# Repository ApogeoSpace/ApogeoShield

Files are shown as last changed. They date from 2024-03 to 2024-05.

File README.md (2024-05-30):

# ApogeoShield
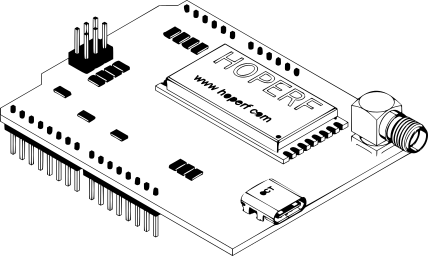
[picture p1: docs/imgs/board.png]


This repository hosts design files for an Arduino shield featuring a HopeRF RFM98 module, optimized for communication at 169 MHz. 
The project is developed by Apogeo Space Srl and allows users to connect and communicate via LoRa with the Apogeo Space IoT network with their own hardware.

## Building your shield

Feel free to utilize the provided files to construct your shields, ensuring compliance with the terms of our [license](LICENSE.md).

Please note that the project is built using KiCad 6, and while compatibility has been tested with later versions, successful importation to other CAD software is not guaranteed.

### BOM

While we do not provide specific sources for all the components needed; however, you can find the actual [BOM](bom.csv) and refer to it when sourcing components.

You can also open an issue or contact us directly for more information if you find it difficult to find certain components.

## What can I do with it?

Once you have built a shield, you can mount it on an Arduino Uno and use our [ApogeoNode](https://github.com/ApogeoSpace/ApogeoNode) library to connect to the Apogeo Space IoT network!

For further information or inquiries, please contact us.

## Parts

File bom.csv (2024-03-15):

Reference | Value | Datasheet | Footprint | Qty | DNP
J1 | Conn_02x03_Odd_Even | ~ | Connector_PinHeader_2.54mm:PinHeader_2x03_P2.54mm_Vertical | 1
J2 | Conn_Coaxial | ~ | Amphenol:SMA_Amphenol_901-143_Horizontal | 1
J4,J5 | Conn_01x06_Pin | ~ | Connector_PinHeader_2.54mm:PinHeader_1x06_P2.54mm_Vertical | 2
J6,J7 | Conn_01x08_Pin | ~ | Connector_PinHeader_2.54mm:PinHeader_1x08_P2.54mm_Vertical | 2
MOD1 | RFM98PW |  | Acies:XCVR_RFM98PW | 1
P1 | USB_C_Plug_USB2.0 | https://www.usb.org/sites/default/files/documents/usb_type-c.zip | Connettori_P:USB_C_Receptacle_GCT_USB4085 | 1
R6,R7,R8,R9 | 1K | ~ | Resistor_SMD:R_1206_3216Metric_Pad1.30x1.75mm_HandSolder | 4
RC1,RC2,RI1,RI2,RO1,RO2,RR2,RS2,RS5 | 560 | ~ | Resistor_SMD:R_1206_3216Metric_Pad1.30x1.75mm_HandSolder | 9
RD2 | 0 | ~ | Resistor_SMD:R_1206_3216Metric_Pad1.30x1.75mm_HandSolder | 1

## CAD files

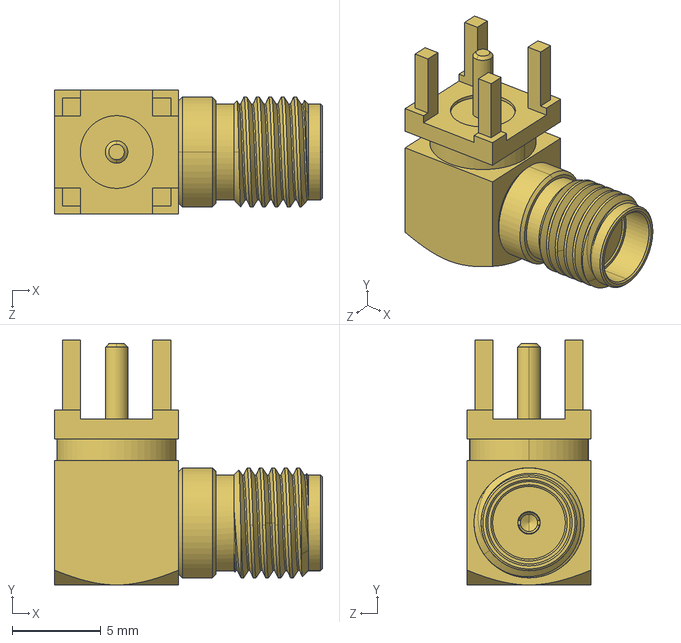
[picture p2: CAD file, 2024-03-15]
mdl/901-143-6RFX.stp
15.1 x 13.8 x 7.00 mm

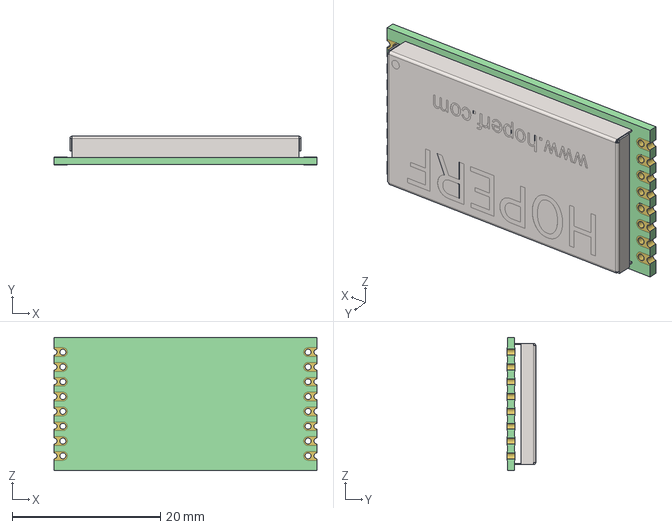
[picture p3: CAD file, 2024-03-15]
mdl/RFM98PW_RFM95PW.STEP
35.5 x 3.87 x 18.0 mm
RFM98PW_RFM95PW
RFM98PW_RFM95PW001

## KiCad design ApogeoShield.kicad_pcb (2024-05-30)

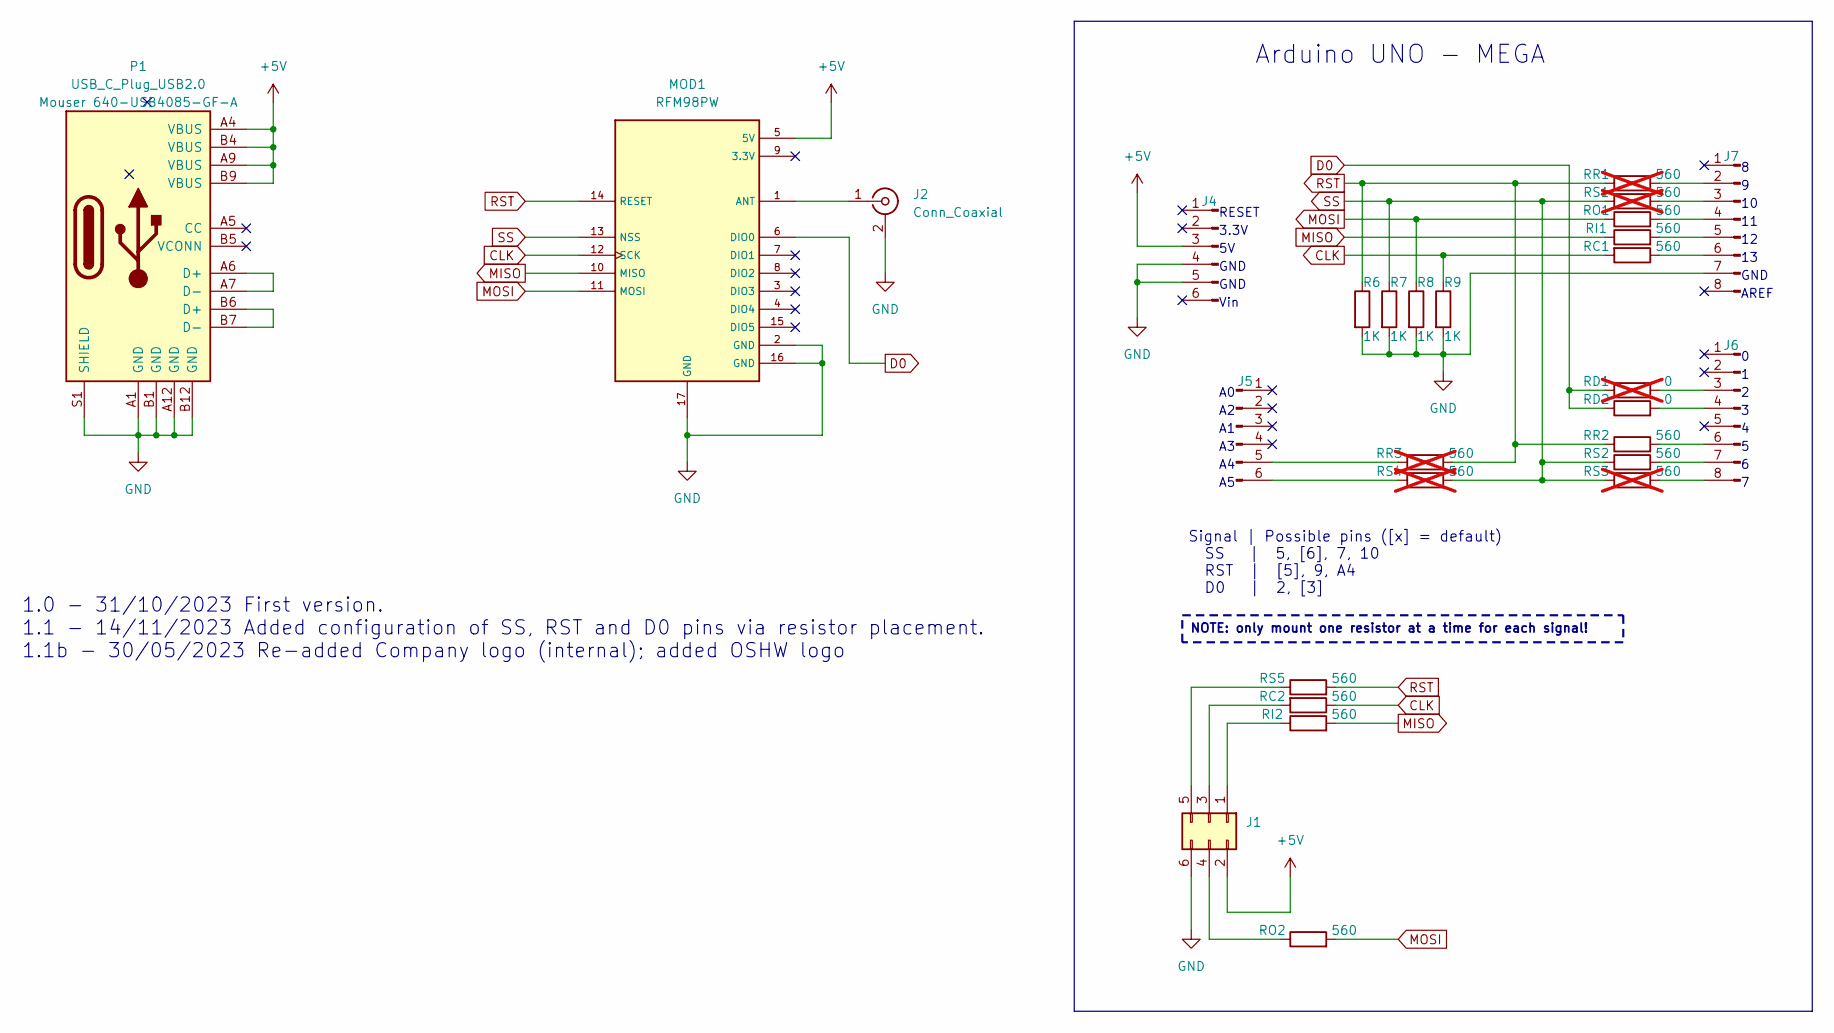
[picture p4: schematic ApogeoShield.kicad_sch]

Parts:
J1: Conn_02x03_Odd_Even; PinHeader_2x03_P2.54mm_Vertical
J2: Conn_Coaxial; SMA_Amphenol_901-143_Horizontal
J4, J5: Conn_01x06_Pin; PinHeader_1x06_P2.54mm_Vertical
J6, J7: Conn_01x08_Pin; PinHeader_1x08_P2.54mm_Vertical
MOD1: RFM98PW; XCVR_RFM98PW
P1: USB_C_Plug_USB2.0; USB_C_Receptacle_GCT_USB4085
R6, R7, R8, R9: 1K; R_1206_3216Metric_Pad1.30x1.75mm_HandSolder
RC1, RC2: 560; R_1206_3216Metric_Pad1.30x1.75mm_HandSolder
RD1: 0; R_1206_3216Metric_Pad1.30x1.75mm_HandSolder; not fitted
RD2: 0; R_1206_3216Metric_Pad1.30x1.75mm_HandSolder
RI1, RI2: 560; R_1206_3216Metric_Pad1.30x1.75mm_HandSolder
RO1, RO2: 560; R_1206_3216Metric_Pad1.30x1.75mm_HandSolder
RR1, RR3: 560; R_1206_3216Metric_Pad1.30x1.75mm_HandSolder; not fitted
RR2: 560; R_1206_3216Metric_Pad1.30x1.75mm_HandSolder
RS1, RS3, RS4: 560; R_1206_3216Metric_Pad1.30x1.75mm_HandSolder; not fitted
RS2, RS5: 560; R_1206_3216Metric_Pad1.30x1.75mm_HandSolder

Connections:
+5V: J1.2, J4.3, MOD1.5 (5V), P1.A4 (VBUS), P1.A9 (VBUS), P1.B4 (VBUS), P1.B9 (VBUS)
CLK: MOD1.12 (SCK), R9.1, RC1.2, RC2.1
D0: MOD1.6 (DIO0), RD1.1, RD2.1
GND: J1.6, J2.2 (Ext), J4.4, J4.5, J7.7, MOD1.2 (GND), MOD1.16 (GND), MOD1.17 (GND), P1.A1 (GND), P1.A12 (GND), P1.B1 (GND), P1.B12 (GND), P1.S1 (SHIELD), R6.2, R7.2, R8.2, R9.2
MISO: MOD1.10 (MISO), RI1.1, RI2.2
MOSI: MOD1.11 (MOSI), R8.1, RO1.1, RO2.2
unnamed: J1.1, RI2.1
unnamed: J1.3, RC2.2
unnamed: J1.4, RO2.1
unnamed: J1.5, RS5.1
unnamed: J2.1 (In), MOD1.1 (ANT)
unnamed: J5.5, RR3.1
unnamed: J5.6, RS4.1
unnamed: J6.3, RD1.2
unnamed: J6.4, RD2.2
unnamed: J6.6, RR2.2
unnamed: J6.7, RS2.2
unnamed: J6.8, RS3.2
unnamed: J7.2, RR1.2
unnamed: J7.3, RS1.2
unnamed: J7.4, RO1.2
unnamed: J7.5, RI1.2
unnamed: J7.6, RC1.1
unnamed: P1.A6 (D+), P1.A7 (D-)
unnamed: P1.B6 (D+), P1.B7 (D-)
RST: MOD1.14 (RESET), R6.1, RR1.1, RR2.1, RR3.2, RS5.2
SS: MOD1.13 (NSS), R7.1, RS1.1, RS2.1, RS3.1, RS4.2

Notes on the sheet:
NOTE: only mount one resistor at a time for each signal!
Vin
3.3V
Arduino UNO - MEGA
GND
Signal | Possible pins ([x] = default) SS | 5, [6], 7, 10 RST | [5], 9, A4 D0 | 2, [3]
RESET
AREF
1.0 - 31/10/2023 First version. 1.1 - 14/11/2023 Added configuration of SS, RST and D0 pins via resistor placement. 1.1b - 30/05/2023 Re-added Company logo (internal); added OSHW logo

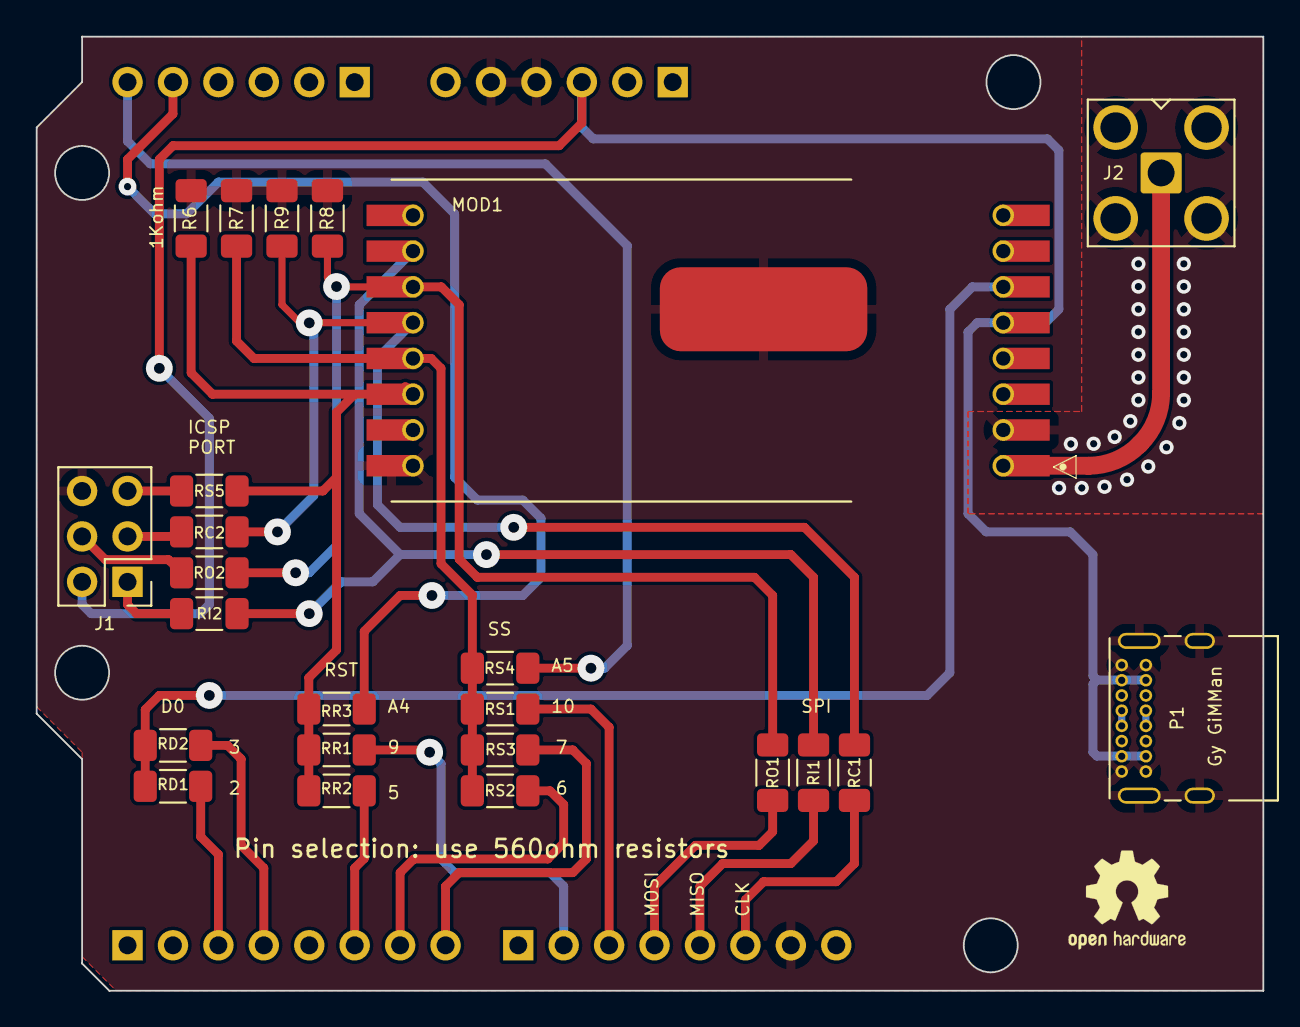
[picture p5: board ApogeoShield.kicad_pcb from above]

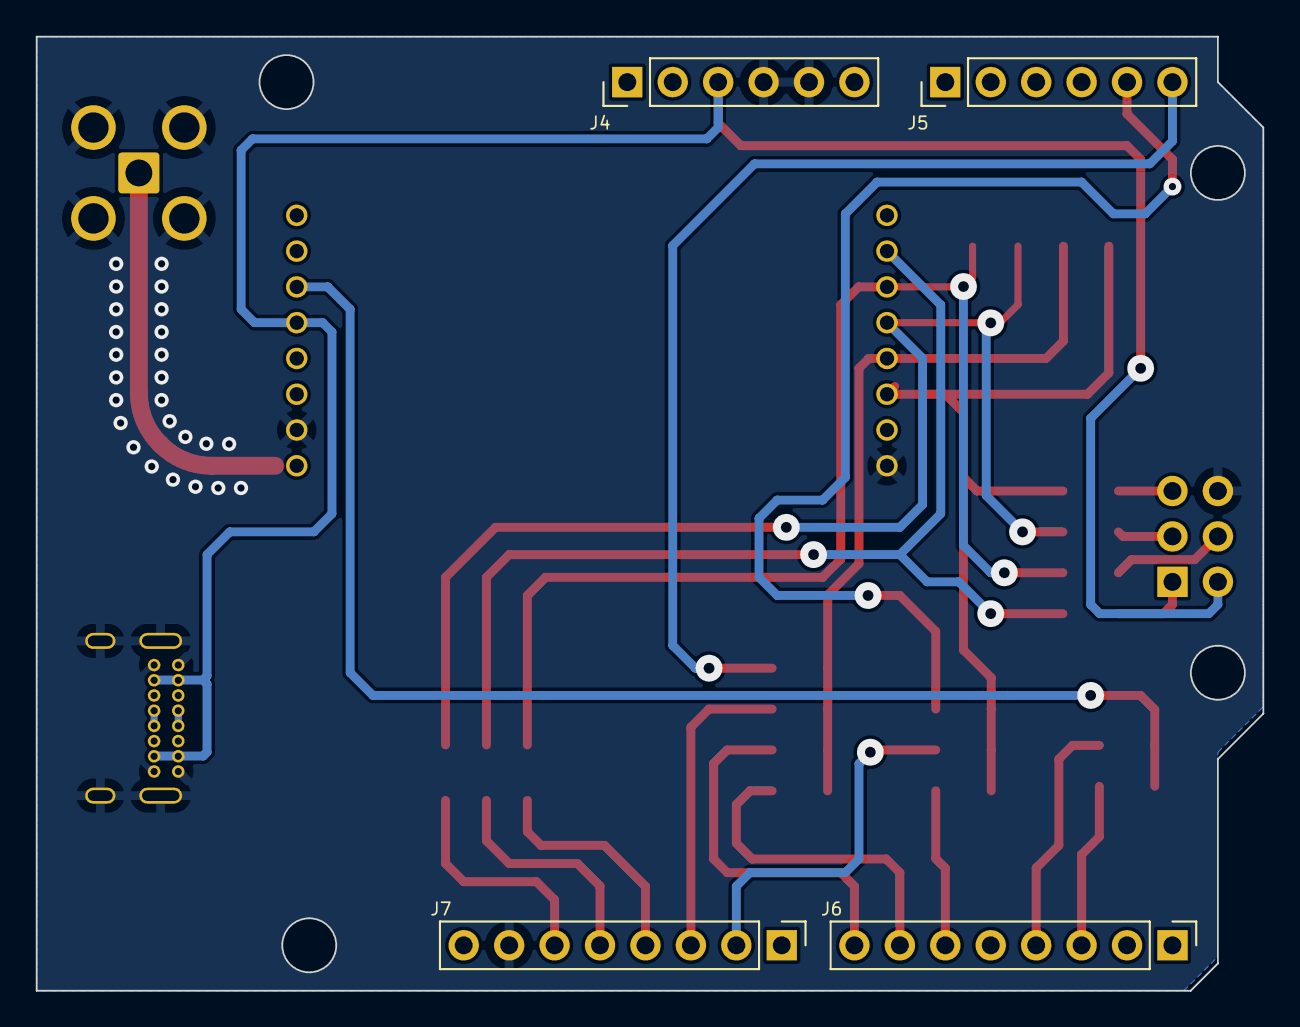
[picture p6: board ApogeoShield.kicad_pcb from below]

Board: 2 copper layers, 68.6 x 53.3 mm, 28 parts (4 on the bottom side), 27 nets.

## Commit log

2024-03-15 Release 0.1
    [901-143-6RFX.stp, Nodo_A_HW.kicad_pcb, Nodo_A_HW.kicad_sch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]
2024-05-30 Release 1.1b
    [ApogeoShield.kicad_pcb, ApogeoShield.kicad_sch]
